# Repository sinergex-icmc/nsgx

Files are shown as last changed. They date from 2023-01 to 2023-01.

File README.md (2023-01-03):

# nsgx
Nodo LoRaWAN para monitorizar el estado de plantas de alcornoque en el proyecto SINERGEX
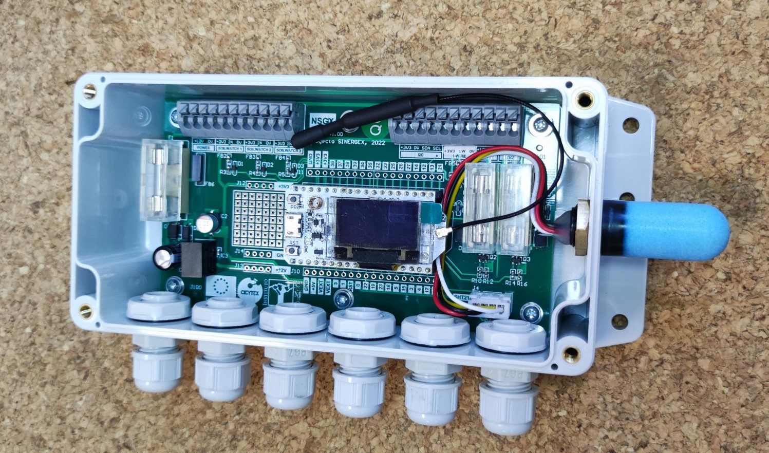
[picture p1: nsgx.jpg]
imagen nodo


**1. Características principales.**
- Microcontrolador Heltec ESP32 LoRa V2.
- Alimentación a 12VDC con regulador conmutado de alta eficiencia,
protección de polaridad inversa y fusible.
- Conectividad WIFI/Bluetooth/LoRa
- 3 canales de entrada para sensores de humedad SOILWATCH.
- 1 canal de entrada para sensor de temperatura DS18B20.
- Medida local de temperatura y humedad (sensor SHT21)
- 2 salidas de transistor para electroválvulas de 12VDC con detección de
rotura de fusible.
- Zona de prototipado.
- Protección inversión de polaridad alim
- Conexiones mediante bornas tipo “cepo”.
- Acceso mediante pasamuros PG7.
- Caja policarbonato IP65.

**2. Descripción y conexionado**
  
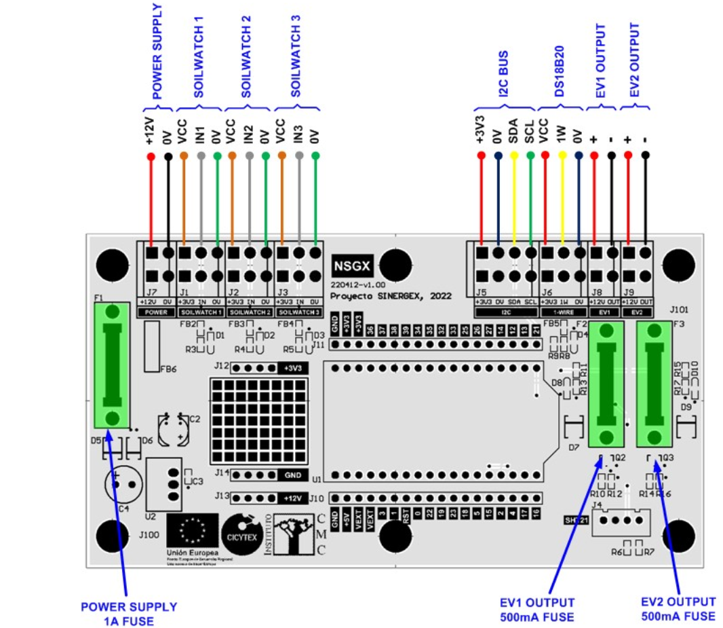
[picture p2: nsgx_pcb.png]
pcb nodo

  
La equivalencia entre las E/S de NSGX y el procesador Heltec ESP32 LoRa
V2 son las siguientes:
| E/S NSGX |Heltec ESP32 LoRa v2.1| DIR |
|---|---|---|
| SENSOR SOILWATCH 1 | 36 |  ANALOG  |
| SENSOR SOILWATCH 2 | 38 |  ANALOG  |
| SENSOR SOILWATCH 3 | 39 |  ANALOG  |
| EV1 OUTPUT | 2 |  OUTPUT  |
| EV2 OUTPUT | 23 |  OUTPUT  |
| EV1 FUSE OPEN | 32 |  INPUT |
| EV2 FUSE OPEN | 33 |  INPUT |
| DS18B20 BUS 1W | 13 | I/O |
| LED | 25 |  OUTPUT  |

**3. Especificaciones técnicas generales.** 
- Alimentación: 12VDC +/-10%
- Consumo máximo: 0.5W
- Microcontrolador: ESP32
- Corriente máxima salida EVs: 500mA
- Temperatura de funcionamiento: 0 ~ 50 ºC
- Temperatura de almacenamiento: -20 ~ 85 ºC
- Grado de protección IP: IP65
- Ancho: 190 mm
- Alto: 100 mm
- Fondo 55 mm
- Peso: 300 g.  
**4. Especificaciones sensor temperatura y humedad local**
- Tipo sensor: SHT21 (SENSIRION)
- Interface: I2C
- Resolución temperatura: 0.1ºC
- Rango de medida: -40 ~ 85ºC
- Precisión típica: +/- 0.3ºC
- Precisión máxima: +/- 1ºC
- Resolución humedad: 1%
- Rango de medida: 0 ~ 100%RH
- Precisión típica: +/- 2%RH
- Precisión máxima: +/- 5%RH

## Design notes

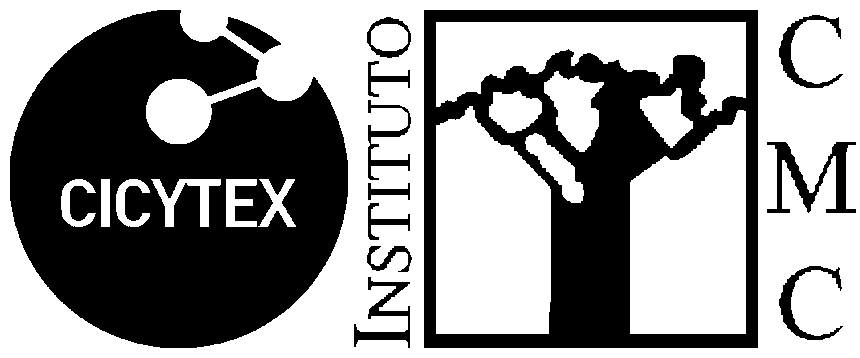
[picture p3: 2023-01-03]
NSGX - 220412 - v1.00/silk_CICYTEX_negro.png

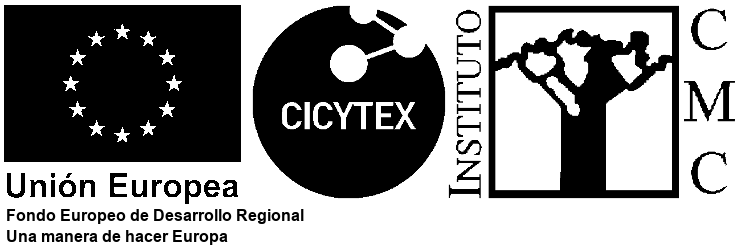
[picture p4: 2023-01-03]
NSGX - 220412 - v1.00/silk_CICYTEX_UE_negro.png

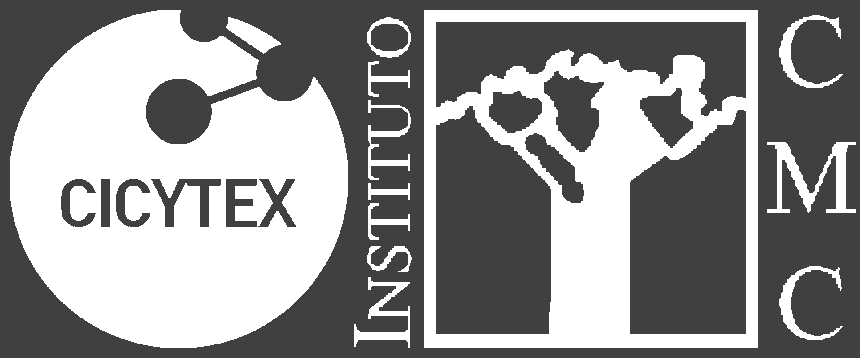
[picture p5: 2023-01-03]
NSGX - 220412 - v1.00/silk_CICYTEX.png

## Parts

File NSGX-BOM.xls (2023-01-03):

Quantity | Designator | Comment | Footprint | LibRef
6 | D1, D2, D3, D4, D8, D10 | UCLAMP3301D | SOD-323 | TRANSIL_UNI_SMA
5 | R9, R12, R13, R16, R17 | 10K | 0603 | RES1
4 | FB2, FB3, FB4, FB5 | MPZ1608S601A | 0603_CAP | FERRITA_FBMJ3216HS800
4 | R3, R4, R5, R8 | 10R | 0603 | RES1
3 | D5, D7, D9 | S2K | SMB | Diode 1N4001
2 | Q2, Q3 | IRLML6344TR | SOT-23 | IRLML6344TR
2 | R6, R7 | 2K2 | 0603 | RES1
2 | R10, R14 | 1K | 0603 | RES1
2 | R11, R15 | 47K | 0603 | RES1
1 | C3 | 100nF | 0603_CAP | CAPACITOR
1 | D6 | SMAJ15A | SMA | TRANSIL_UNI_SMA
1 | FB6 | FERRITA_2773021447 | FERRITA_2773021447 | FERRITA_2773021447
3 | J12, J13, J14 | CON4 | HDR1X4 | CON4
2 | F2, F3 | 0.5A | FUSE1 | FUSE2
2 | J10, J11 | CON18 | HDR1X18 | CON18
1 | C2 | 100uF/6V3 | CAP-0605 | CAPACITOR POL
1 | C4 | 100uF/50V | CAP150RP | CAPACITOR POL
1 | F1 | 1A/250V | FUSE1 | FUSE1
1 | J1 | SoilWatch1 | DG250-3.5-03-P | CON3
1 | J2 | SoilWatch2 | DG250-3.5-03-P | CON3
1 | J3 | SoilWatch3 | DG250-3.5-03-P | CON3
1 | J4 | SHT21 | JST-XH-2.54-4PIN | CON4
1 | J5 | AUX I2C | DG250-3.5-04-P | CON4
1 | J6 | DS18B20 | DG250-3.5-03-P | CON3
1 | J7 | CON2 | DG250-3.5-02-P | CON2
1 | J8 | EV1 OUT | DG250-3.5-02-P | CON2
1 | J9 | EV2 OUT | DG250-3.5-02-P | CON2
1 | U1 | WiFi_LoRa_32_V2 | WiFi_LoRa_32_V2 | WiFi_LoRa_32_V2
1 | U2 | K7803-500 | K78XX-500 | 78XX
 | NSGX - 220412 - v1.00

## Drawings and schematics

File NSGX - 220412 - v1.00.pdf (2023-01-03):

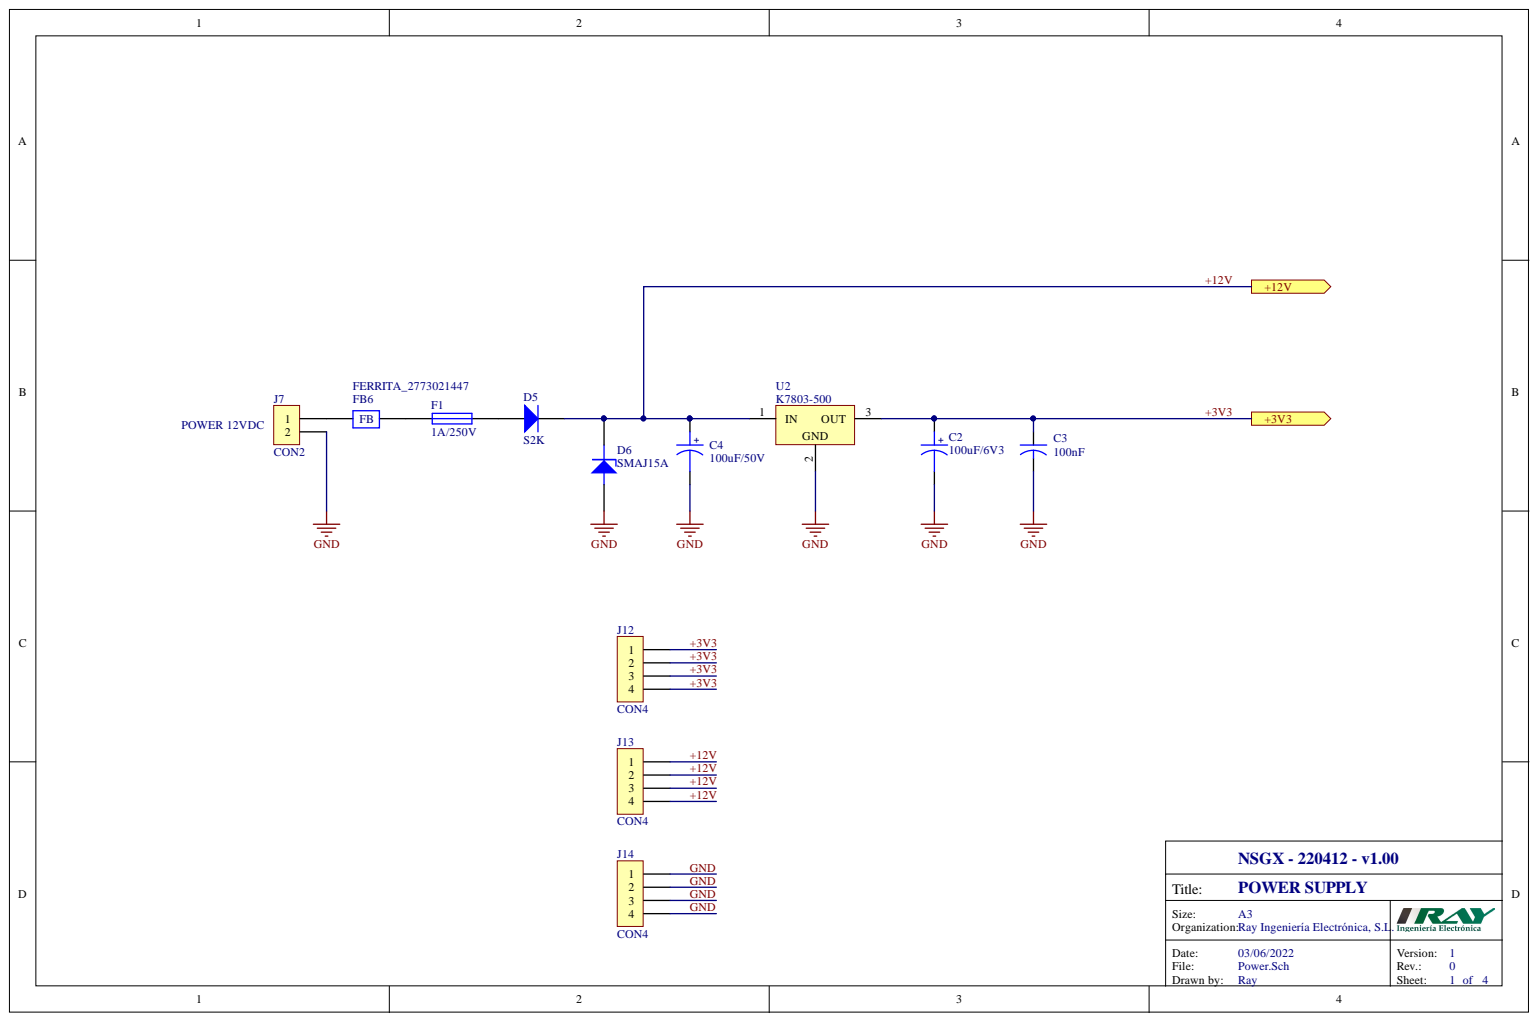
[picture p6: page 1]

Size: A3 Organization: Ray Ingeniería Electrónica, S.L.

Date: 03/06/2022 File: Power.Sch Drawn by: Ray | Version: 1 Rev.: Sheet: 1 of 4

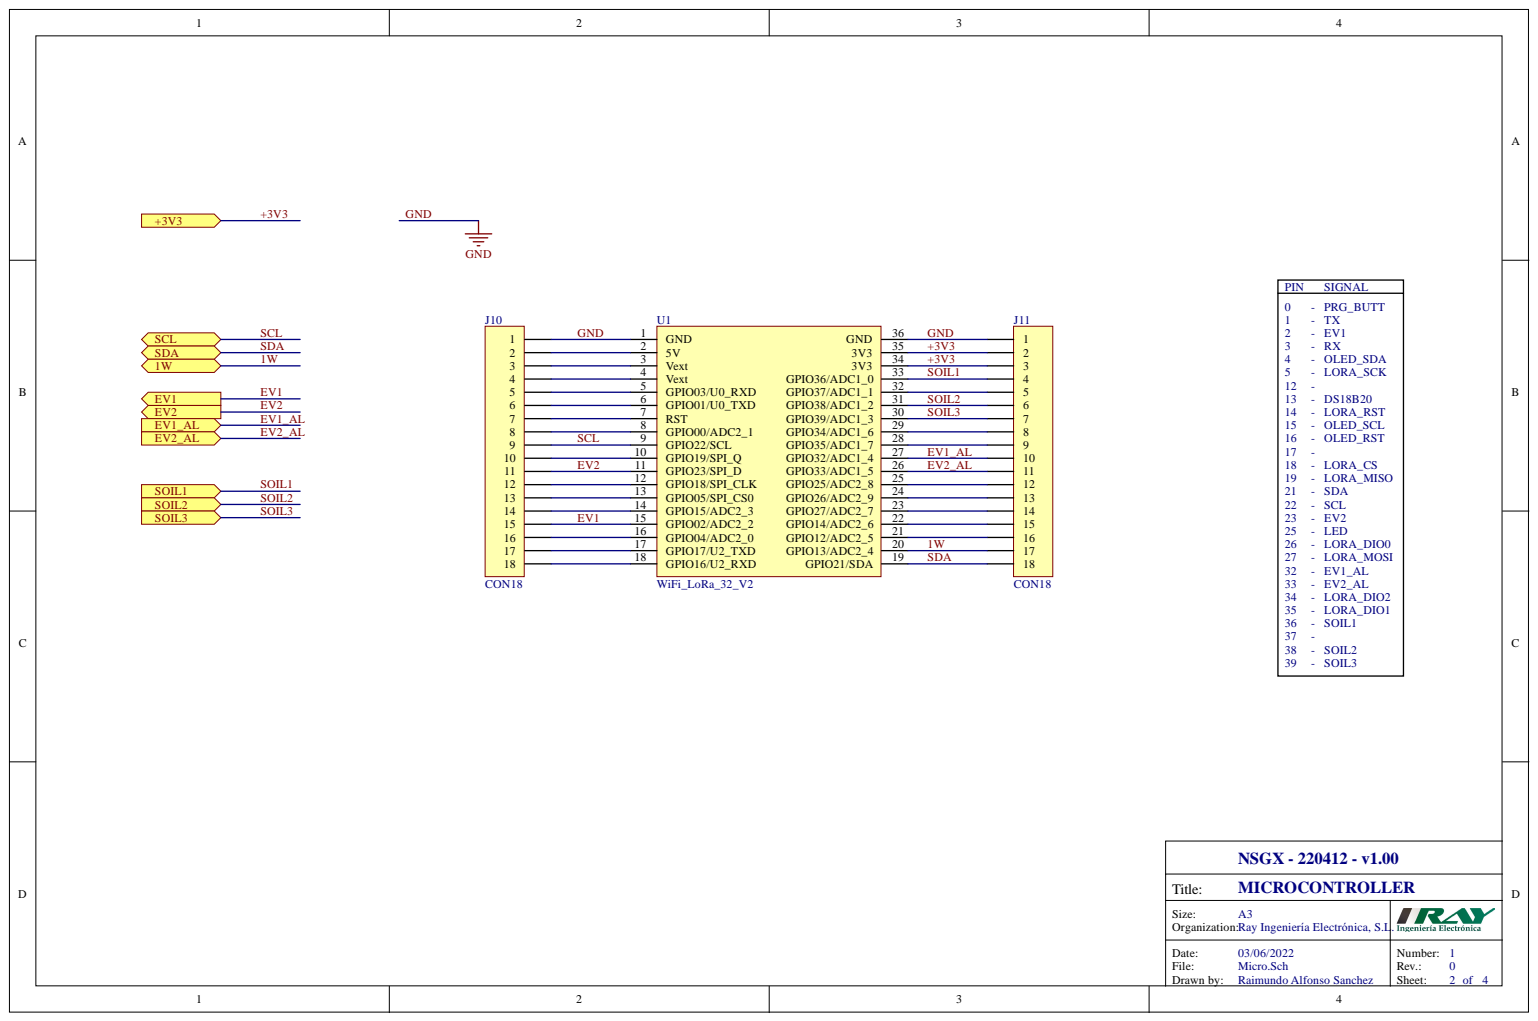
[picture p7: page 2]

2 | 3 5 +3 V 3
3 | 3 4 +3 V 3
4 | 3 3 SOIL 1
5 | 3 2

6 | 3 1 SOIL 2
7 | 3 0 SOIL 3
8 | 2 9

SCL 9 | 2 8

1 2 | 2 5
1 3 | 2 4
1 4 | 2 3

1 6 | 2 1
1 7 | 2 0 1 W
1 8 | 1 9 SD A

Size: A 3 Organ izat i o n : Ray In gen ier ía E lect r ó n ica, S.L | .

Date: 0 3 / 0 6 / 2 0 2 2 Fi le: Micro.Sch Draw n b y : Raimu n d o A lfo n s o Sanchez | N umber: 1 Sheet : o f

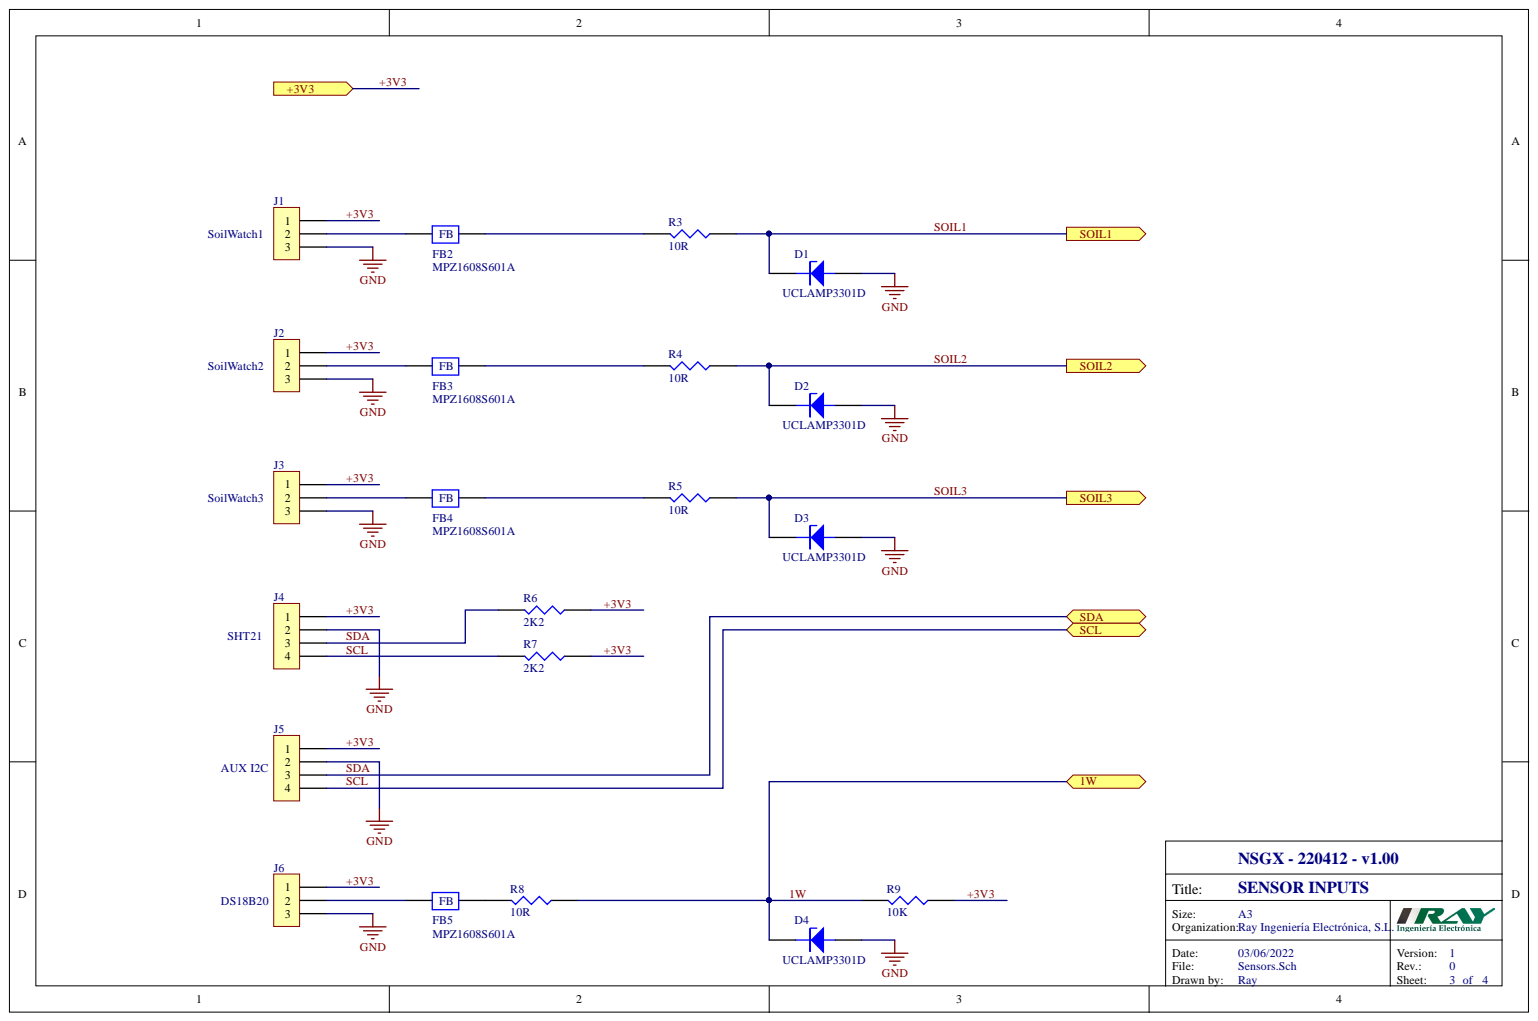
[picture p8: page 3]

SDA

Size: A3 Organization: Ray Ingeniería Electrónica, S.L.

Date: 03/06/2022 File: Sensors.Sch Drawn by: Ray | Version: 1 Sheet: 3 of 4

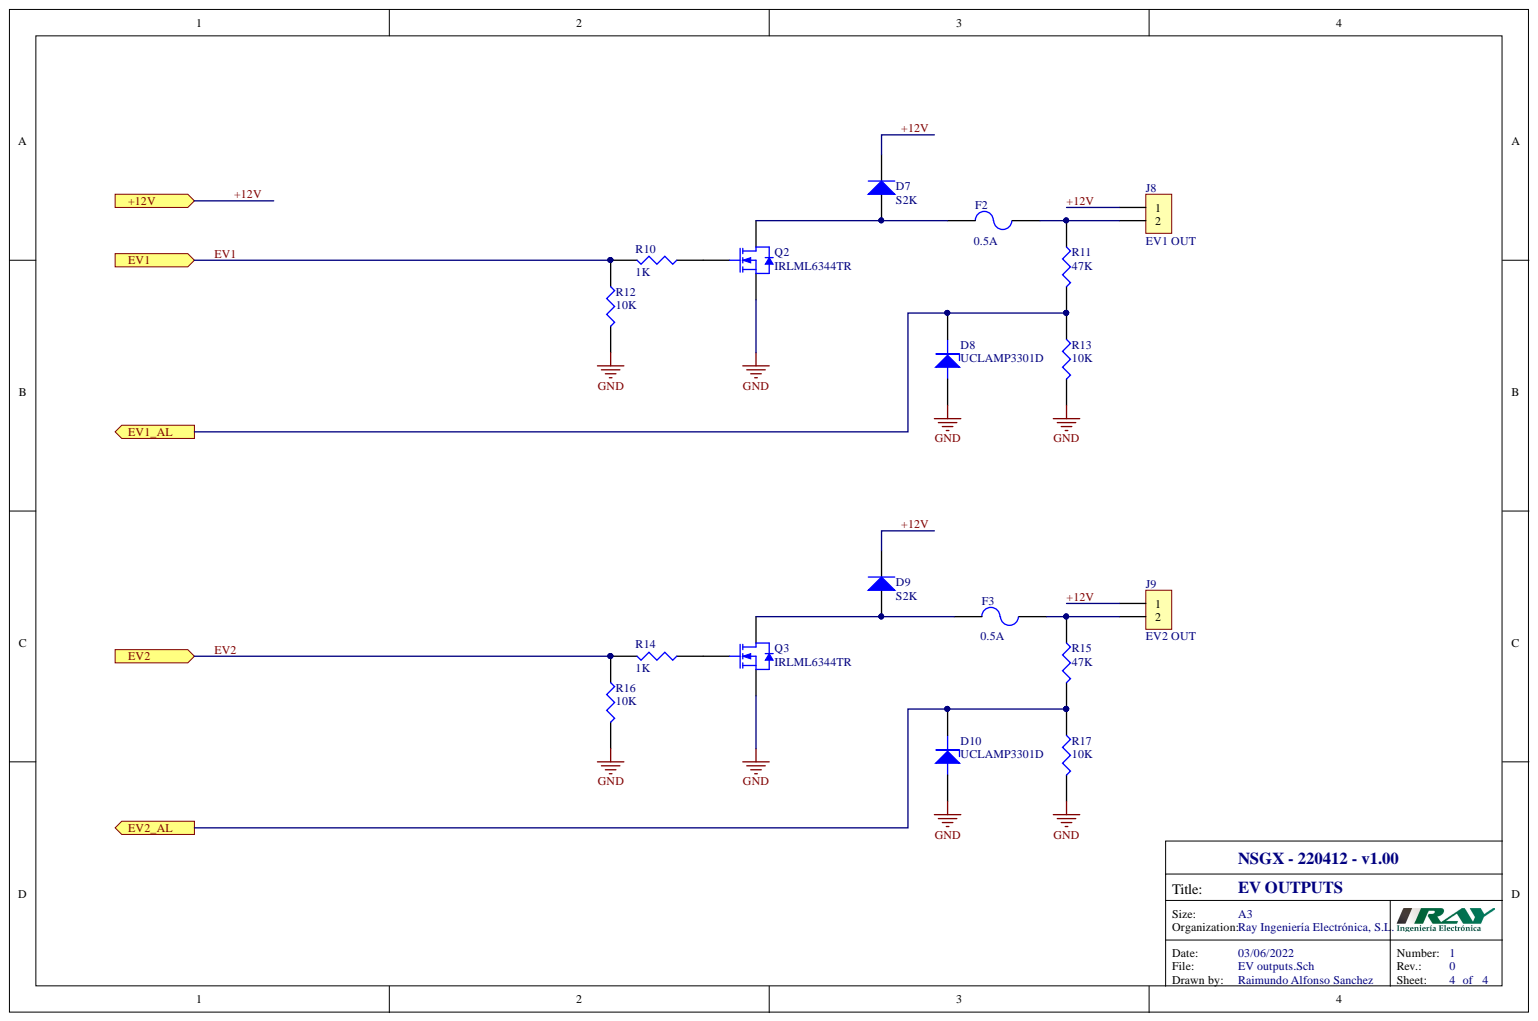
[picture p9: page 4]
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

Date: 0 3 / 0 6 / 2 0 2 2 Fi le: E V o u t p u t s.Sch Draw n b y : Raimu n d o A lfo n s o Sanchez | N umber: 1 Sheet : o f

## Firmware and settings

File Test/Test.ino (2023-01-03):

/**************************************************************************
 @FILE:         Test.cpp
 @AUTHOR:       Raimundo Alfonso
 @COMPANY:      Ray Ingeniería Electronica, S.L.
 @DESCRIPTION:  Test placa 220412 - v1.00
 @BOARD:        WiFi LoRa 32 (V2)
 @MICRO:        ESP32
  
 @VERSIONS:
  01-06-2022 - v1.00 :
  - primera versión
  
**************************************************************************/
#include <Wire.h>
#include <OneWire.h>
#include <DallasTemperature.h>
#include "SHT2x.h"

#define SOIL1       36
#define SOIL2       38
#define SOIL3       39
#define EV1         2
#define EV2         23    // Cambiamos pin original 12 a pin 23 
#define EV1_AL      32
#define EV2_AL      33
#define DS18B20     13
#define LED         25


// DS18B20...
OneWire oneWire(DS18B20);
DallasTemperature ds18b20(&oneWire);

// SHT21...
SHT2xClass SHT2x;


void menu_inicio(void){ 
  Serial.println("Test placa 220412 - v1.00");
  Serial.println("Ray Ingenieria Electronica, S.L. - 2022 ");  
  Serial.println();
}

int test = 0;
float temperature = 0;
float humidity = 0;           
float dew_point = 0; 
float temperature2 = 0;

// Timer
hw_timer_t * timer = NULL;
portMUX_TYPE timerMux = portMUX_INITIALIZER_UNLOCKED;

void IRAM_ATTR onTimer(){
  char c = 0;
  String inString = "";
  
  // Increment the counter and set the time of ISR
  portENTER_CRITICAL_ISR(&timerMux);
  
  while (Serial.available() > 0) {
    c = Serial.read();   
    inString += (char)c;    
  }    
  if(c != 0){
    inString.trim();
    Serial.println(inString);
    if(inString == ""){
      test++;
    }
    if(inString == "r" || inString == "R"){
      test--;
      if(test < 1) test = 1;
    }
  }
  Serial.flush();
  
  portEXIT_CRITICAL_ISR(&timerMux);
}

void setup(){ 
  pinMode(EV1, OUTPUT);
  pinMode(EV2, OUTPUT);
  pinMode(EV1_AL, INPUT);
  pinMode(EV2_AL, INPUT);
  pinMode(LED, OUTPUT);

 
  // Configura puertos serie...
  Serial.begin(9600); 
  delay(100);

  analogReadResolution(12);
  //analogSetWidth(10);                           
  //analogSetAttenuation((adc_attenuation_t)0);   

  // Mensaje inicial...
  menu_inicio();

  // SHT21...
  Wire.begin();

  // DS18B20...
  Serial.println("Temperature sensor init...");
  ds18b20.begin();
  ds18b20.setWaitForConversion(true);
  ds18b20.setResolution(12);
  Serial.print("Found ");
  Serial.print(ds18b20.getDeviceCount(), DEC);
  Serial.println(" devices.");
  
  
  // Timer cada 100mS...
  // Use 1st timer of 4 (counted from zero).
  // Set 80 divider for prescaler (see ESP32 Technical Reference Manual for more
  // info).
  timer = timerBegin(0, 80, true);
  // Attach onTimer function to our timer.
  timerAttachInterrupt(timer, &onTimer, true);
  // Set alarm to call onTimer in microseconds
  // Repeat the alarm (third parameter)
  timerAlarmWrite(timer, 100000, true);
  // Start an alarm
  timerAlarmEnable(timer);
 

  Serial.println();
  Serial.println("Habilita NL y CR");
  Serial.println("Pulsa 'INTRO' para avanzar por el test y 'r' para retrodecer.");
  Serial.println();
} 



void loop(){ 

  switch(test){
    case 1:
      testSalidas();
      break;    
    case 2:
      testSensores();
      break;      
    case 3:
      testFin();
      break;               
  }
} 

void testFin(void){
  Serial.println();
  Serial.println("TEST FINALIZADO");
  while(1);  
}

void testSalidas(void){
  static boolean primeraVez = true;

  if(primeraVez){
    Serial.println("Test de salidas digitales...");
    primeraVez = false;
  }
  
  Serial.println("Salida EV1");
  digitalWrite(EV1, HIGH);
  delay(1000);
  Serial.print("Alarma EV1: ");
  if(digitalRead(EV1_AL))
    Serial.println("on");
  else
    Serial.println("off");
  digitalWrite(EV1, LOW);
  delay(1000);

  Serial.println("Salida EV2");
  digitalWrite(EV2, HIGH);
  delay(1000);
  Serial.print("Alarma EV2: ");
  if(digitalRead(EV2_AL))
    Serial.println("on");
  else
    Serial.println("off");  
  digitalWrite(EV2, LOW);
  delay(1000);

  Serial.println();

}

void testSensores(void){
  static boolean primeraVez = true;
  int mv;

  if(primeraVez){
    Serial.println("Test de sensores...");
    primeraVez = false;
  }

  // Activamos led de la placa
  digitalWrite(LED, HIGH);

  // Lectura de los sensores SOILWATCH...
  Serial.println("SOILWATCH...");
  mv = map(analogRead(SOIL1), 0, 4095, 0, 3300);
  Serial.print("SoilWatch1 : ");
  Serial.println(mv);

  mv = map(analogRead(SOIL2), 0, 4095, 0, 3300);
  Serial.print("SoilWatch2 : ");
  Serial.println(mv);

  mv = map(analogRead(SOIL3), 0, 4095, 0, 3300);
  Serial.print("SoilWatch3 : ");
  Serial.println(mv);
  Serial.println();

  // Lectura del sensor SHT21...
  leeSHT21();  
  Serial.println("SHT21...");
  Serial.print("Temperatura: ");
  Serial.print(temperature);
  Serial.println(" ºC");
  Serial.print("Humedad    : ");
  Serial.print(humidity);
  Serial.println(" %");
  Serial.print("Pto. rocio : ");
  Serial.print(dew_point);
  Serial.println(" ºC");
  Serial.println();


  // Lectura del sensor DS18B20...
  Serial.println("DS18D20...");
  ds18b20.requestTemperatures(); 
  temperature2 = ds18b20.getTempCByIndex(0);
  if((int)temperature2 >= 85 || (int)temperature2 <= -50){
    Serial.println(F("Temperatura: FALLO"));
    Serial.println();
  }else{
    Serial.print("Temperatura: ");
    Serial.print(temperature2,1);
    Serial.println(" ºC");
  }
  Serial.println();
  Serial.println();  

  // Desactivamos led de la placa
  digitalWrite(LED, LOW);

  delay(2000);
}

// Lectura del sensor SHT21 sin bloqueo...
void leeSHT21(void){
  unsigned long timeOutSensor = 0; 
  float t;
  float h;
  boolean temperature_ok = false;
  boolean humidity_ok = false;
 
  SHT2x.PrepareTemperatureNoHold();
  timeOutSensor = millis();  
  do{ 
    if(SHT2x.GetTemperatureNoHold(&t)){
      temperature_ok = true;     
    }
  }while(temperature_ok == false && (millis() - timeOutSensor) < 100L);
  
  SHT2x.PrepareHumidityNoHold();
  timeOutSensor = millis();  
  do{ 
    if(SHT2x.GetHumidityNoHold(&h)){
      humidity_ok = true;   
    }
  }while(humidity_ok == false && (millis() - timeOutSensor) < 100L);

  if(temperature_ok && humidity_ok){
    temperature = t;
    humidity = h;     
    dew_point = calcDewpoint(h,t); 
  }else{
    temperature = 0;
    humidity = 0;           
    dew_point = 0;   
  }
}

float calcDewpoint(float humi, float temp) {
  float k;
  k = log(humi/100) + (17.62 * temp) / (243.12 + temp);
  return 243.12 * k / (17.62 - k);
}

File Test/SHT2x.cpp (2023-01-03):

/*
  SHT2x - A Humidity Library for Arduino.

  Supported Sensor modules:
    SHT21-Breakout Module - http://www.moderndevice.com/products/sht21-humidity-sensor
	SHT2x-Breakout Module - http://www.misenso.com/products/001
	
  Created by Christopher Ladden at Modern Device on December 2009.
  Modified by Paul Badger March 2010
  
  Modified by www.misenso.com on October 2011:
	- code optimisation
	- compatibility with Arduino 1.0

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
  You should have received a copy of the GNU Lesser General Public
  License along with this library; if not, write to the Free Software
  Foundation, Inc., 51 Franklin St, Fifth Floor, Boston, MA  02110-1301  USA
*/

#include <inttypes.h>
#include <Wire.h>
#include "Arduino.h"
#include "SHT2x.h"



/******************************************************************************
 * Global Functions
 ******************************************************************************/

SHT2xClass::SHT2xClass()
{
	measTempReady = false;
	measHumReady = false;
	measuringTemp = false;
	measuringHum = false;
}	
 
/**********************************************************
 * GetHumidity
 *  Gets the current humidity from the sensor.
 *
 * @return float - The relative humidity in %RH
 **********************************************************/
float SHT2xClass::GetHumidity(void)
{
	return (-6.0 + 125.0 / 65536.0 * (float)(readSensor(eRHumidityHoldCmd)));
}

boolean SHT2xClass::GetHumidityNoHold(float *h)
{
	uint16_t a;

	if(measuringHum == true){
		a = readSensorNoHoldRead();
		if(measHumReady){
			*h = (-6.0 + 125.0 / 65536.0 * (float)(a));
			return(true);
		}else
			return(false);
	}else{
		return(false);
	}
}

/**********************************************************
 * GetTemperature
 *  Gets the current temperature from the sensor.
 *
 * @return float - The temperature in Deg C
 **********************************************************/
float SHT2xClass::GetTemperature(void)
{
	return (-46.85 + 175.72 / 65536.0 * (float)(readSensor(eTempHoldCmd)));
}

boolean SHT2xClass::GetTemperatureNoHold(float *t)
{
	uint16_t a;

	if(measuringTemp == true){
		a = readSensorNoHoldRead();
		if(measTempReady){
			*t = (-46.85 + 175.72 / 65536.0 * (float)(a));
			return(true);
		}else
			return(false);
	}else{
		return(false);
	}
}


/******************************************************************************
 * Private Functions
 ******************************************************************************/

uint16_t SHT2xClass::readSensor(uint8_t command)
{
    uint16_t result;

    Wire.beginTransmission(eSHT2xAddress);	//begin
    Wire.write(command);					//send the pointer location
    delay(100);
    Wire.endTransmission();               	//end

    Wire.requestFrom(eSHT2xAddress, 3);
    while(Wire.available() < 3) {
      ; //wait
    }

    //Store the result
    result = ((Wire.read()) << 8);
    result += Wire.read();
	result &= ~0x0003;   // clear two low bits (status bits)
    return result;
}


void SHT2xClass::readSensorNoHold(uint8_t command){
	uint16_t result;

    Wire.beginTransmission(eSHT2xAddress);	//begin
    Wire.write(command);					//send the pointer location
    Wire.endTransmission();               	//end
}


uint16_t SHT2xClass::readSensorNoHoldRead(void){
	uint16_t result;
	
    Wire.requestFrom(eSHT2xAddress, 3);
    if(Wire.available() < 3) return -1;
      
    //Store the result
    result = ((Wire.read()) << 8);
    result += Wire.read();
	if(bitRead(result,1) == 0){
		measTempReady = true;
		measuringTemp = false;		
	}else{
		measHumReady = true;
		measuringHum = false;
	}
	
	result &= ~0x0003;   // clear two low bits (status bits)
    return result;
	
}

void SHT2xClass::PrepareTemperatureNoHold(void){
	measTempReady = false;
	measuringTemp = true;
	readSensorNoHold(eTempNoHoldCmd);
}

void SHT2xClass::PrepareHumidityNoHold(void){
	measHumReady = false;
	measuringHum = true;
	readSensorNoHold(eRHumidityNoHoldCmd);
}
